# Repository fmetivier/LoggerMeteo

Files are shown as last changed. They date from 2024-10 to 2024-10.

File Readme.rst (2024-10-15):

=====================================================================
LoggerMeteo: Une station météo autonome contrôlé par un Arduino Nano
=====================================================================

Principe
=========

LoggerMeteo est une station connectée à un datalogger autonome fonctionnant sur piles AA/AAA. Ses propriétés sont les suivantes

* l'enregistreur est contrôlé par un Arduino Nano, modifié dans le but de réduire la consommation d'énergie, tout en gardant l'instrument simple à manipuler et à programmer ;
* il enregistre la température, la pression, l'humidité et la teneur en gaz à l'aide d'un capteur Adafruit BME680 ;
* les données sont stockées sur un lecteur de carte SD uPesy ;
* le temps est enregistré par une horloge RTC1307 (toujours d'Adafruit)
* il peut-être emballé dans un "abri" météo TFA Dostmann

Tous les composants sont soudés sur une carte PCB conçue avec Fritzing.
L'enregistreur est facile à construire (il fait partie d'un cours d'étudiant de premier cycle), facile à utiliser (il suffit de retirer la carte SD de temps en temps pour charger les données qui sont écrites sur un fichier texte ascii), et est indépendant de tout réseau et logiciel propriétaire.

Avec un taux d'échantillonnage de 15 minutes, il fonctionne plus de cinq mois avec 3 piles AAA ou 11 mois avec 3 piles AA. Il est destiné à être déployé dans des endroits où la connexion est absente ou hasardeuse.

Coût
====
Le coût est donné pour les composants que j'utilise. Ils sont indicatifs et peuvent varier en fonction du fournisseur.

.. list-table:: 
  :header-rows: 1

  * - Composant
    - Prix (€ TTC)
  * - Arduino Nano
    - 25.90
  * - DS1307 RTC Clock (Ada 3296)
    - 9.8
  * - lecteur de cartes uPesy SD
    - 7.20
  * - Coupleur de piles
    - 2.00
  * - Carte PCB
    - 5.00
  * - Carte SD  (8Go)
    - 9.5
  * - Piles
    - 2.0
  * - Abri TFA Dostmann
    - 14.00
  * - Capteur ADA3660
    - 26,4
  * - **Total**
    - **101,8**

Liens
=====

* https://morpho.ipgp.fr/metivier/public/ScEd/build/html/Datalogger.html
* https://morpho.ipgp.fr/metivier/public/Howto/build/html/Arduino.html

Images
======

Dispositif avec Piles AAA
-------------------------
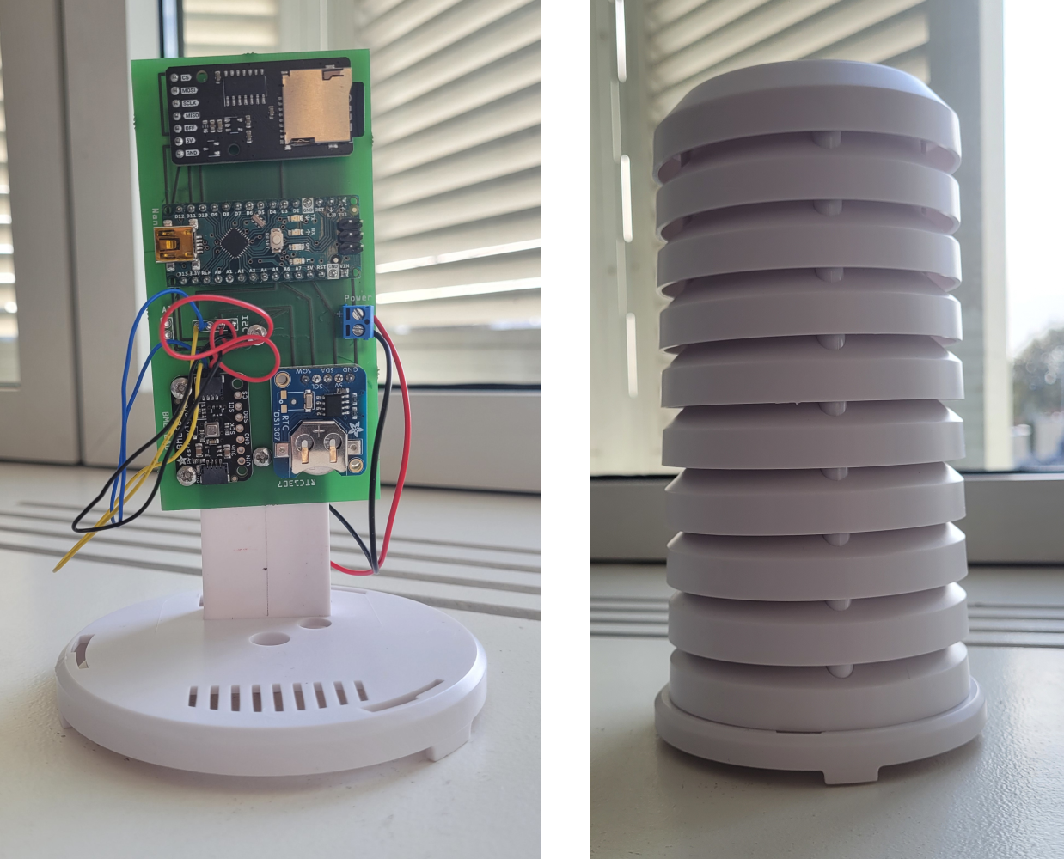
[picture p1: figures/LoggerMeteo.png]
breadboard


Breadboard 
----------

Le lecteur de carte est figuré par les emplacements des headers. Idem pour le BME680. Le BME est vissé. 
Sa connection se fait en soudant les quatres fils de la connexion I2C ce qui permet, si d'aventure le capteur lache, de le changer facilement.

breadboard

Fritzing
--------

pcb

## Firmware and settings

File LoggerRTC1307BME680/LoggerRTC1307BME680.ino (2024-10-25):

/*

Nano Logger + BME 680
Measurements : temperature, humidity, pressure, gaz content
Time step: DT
Storage: SD card
Clock : DS1307

last tested:
Author: F. Métivier

CC-By SA 4.0 
*/

#include "LowPower.h"

#include "Wire.h"
#include <RTClib.h> 
#define ADRESSE_I2C_RTC 0x68 // Adresse I2C de l'horloge RTC
RTC_DS1307 rtc;

const int pullupPin = 2; // reçoit le signal 1Hz du DS1307 
const int DT=900; // interval de emsures (s)
volatile int jedors = 0; // compteur de réception du signal 1Hz

/*
 * Carte SD
 */
#include <SPI.h>
#include <SD.h>

const int chipSelect = 10; // CS pin de la carte SD sur Nano
const int SDOFFPIN = 3; // éteindre le lecteur

Sd2Card card;
SdVolume volume;
SdFile root;

//BME680 lib
#include <Adafruit_Sensor.h>
#include "Adafruit_BME680.h"
#define SEALEVELPRESSURE_HPA (1013.25)
#define ADRESSE_I2C_BME 0x77 // Adresse BME

Adafruit_BME680 bme;
const int BMEPIN = 4;

void setup()
{
  Serial.begin(57600); // pour affichage dans le moniteur série
  delay(10);
  
  Wire.begin();

  // RTC
  Wire.beginTransmission(ADRESSE_I2C_RTC);
  rtc.begin();
  rtc.writeSqwPinMode(DS1307_SquareWave1HZ);
  DateTime now = rtc.now();
  Wire.endTransmission();

  pinMode(pullupPin,INPUT_PULLUP);
  attachInterrupt(digitalPinToInterrupt(pullupPin),jeCompte,FALLING);


  // BME
  pinMode(BMEPIN,OUTPUT);
  digitalWrite(BMEPIN,LOW);

  // SD
  pinMode(SDOFFPIN,OUTPUT);
  digitalWrite(SDOFFPIN,HIGH);
  delay(1000);

  if (!SD.begin(chipSelect)){
    Serial.println("problème avec le lecteur SD");
  }
  char buff[] = "démarrage hh:mm:ss DDD, DD MM YYYY";
  Serial.println(now.toString(buff));
  delay(100);

  digitalWrite(SDOFFPIN,LOW);

}

void loop()
{


      LowPower.powerDown(SLEEP_FOREVER,ADC_OFF,BOD_OFF);
      if (jedors % DT == 0) {
        // arrêt des interruption
        detachInterrupt(digitalPinToInterrupt(pullupPin));
        // démarrage série
        Serial.begin(57600);
        delay(100);
        // récupération de la date
        Wire.begin();
        Wire.beginTransmission(ADRESSE_I2C_RTC);
        DateTime now = rtc.now();
        Wire.endTransmission();
        delay(100);

        // récupération des mesures
        digitalWrite(BMEPIN,HIGH);
        delay(10);
        Wire.beginTransmission(ADRESSE_I2C_BME);
        bme.begin();
        bme.performReading();
        Wire.endTransmission();
        digitalWrite(BMEPIN,LOW);

        // récupération voltage des piles    
        float Voltage = analogRead(A0)*5.0/1023.0;
                  
        Serial.print(now.year());
        Serial.print(F(","));
        Serial.print(now.month());
        Serial.print(F(","));
        Serial.print(now.day());
        Serial.print(F(","));
        Serial.print(now.hour());
        Serial.print(F(","));
        Serial.print(now.minute());
        Serial.print(F(","));
        Serial.print(now.second());
        Serial.print(F(","));
        Serial.print(bme.temperature);
        Serial.print(F(","));
        Serial.print(bme.pressure);
        Serial.print(F(","));
        Serial.print(bme.humidity);
        Serial.print(F(","));
        Serial.print(bme.gas_resistance);
        Serial.print(F(","));
        Serial.print(Voltage);
        Serial.print("\n");

        // réveil lecteur SD
        digitalWrite(SDOFFPIN,HIGH);
        delay(10);
        // écriture carte
        if (SD.begin(chipSelect)){
          File dataFile = SD.open("DATALOG.TXT", FILE_WRITE);
        
          if (dataFile) {
          // if the file is available, write to it:
            dataFile.print(now.year());
            dataFile.print(F(","));
            dataFile.print(now.month());
            dataFile.print(F(","));
            dataFile.print(now.day());
            dataFile.print(F(","));
            dataFile.print(now.hour());
            dataFile.print(F(","));
            dataFile.print(now.minute());
            dataFile.print(F(","));
            dataFile.print(now.second());
            dataFile.print(F(","));
            dataFile.print(bme.temperature);
            dataFile.print(F(","));
            dataFile.print(bme.pressure);
            dataFile.print(F(","));
            dataFile.print(bme.humidity);
            dataFile.print(F(","));
            dataFile.print(bme.gas_resistance);
            dataFile.print(F(","));
            dataFile.print(Voltage);
            dataFile.print("\n");   
            dataFile.close();  
        } else {
          Serial.println("Pas de fichier ?");  
        }
        } else {
          Serial.println("Pas de carte ?");
        }
        
        delay(10);
        //mise en sommeil lecteur SD
        digitalWrite(SDOFFPIN,LOW);

        // arrêt Série
        Serial.end();
        // redémarrage interruptions
        attachInterrupt(digitalPinToInterrupt(pullupPin),jeCompte,FALLING);  
      }

} //end void

void jeCompte(){
  jedors++; 
}

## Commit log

2024-10-08 ajout image capteur et commentaires sur les images
2024-10-15 erreur de calcul
2024-10-23 modification code arduino
2024-10-25 Modif code arduino
